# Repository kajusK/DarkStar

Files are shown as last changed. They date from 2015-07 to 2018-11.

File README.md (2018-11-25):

New version!
============

There's a whole new version with mutch more features and power:
https://github.com/kajusK/Darkstar-Mk.II/

DarkStar headlamp
=================

Small, lightweight and waterproof LED headlamp with two Cree XP-G2 leds. Can be
used in biking, caving, mine exploration, hiking... But **always** carry a
**backup** light source.

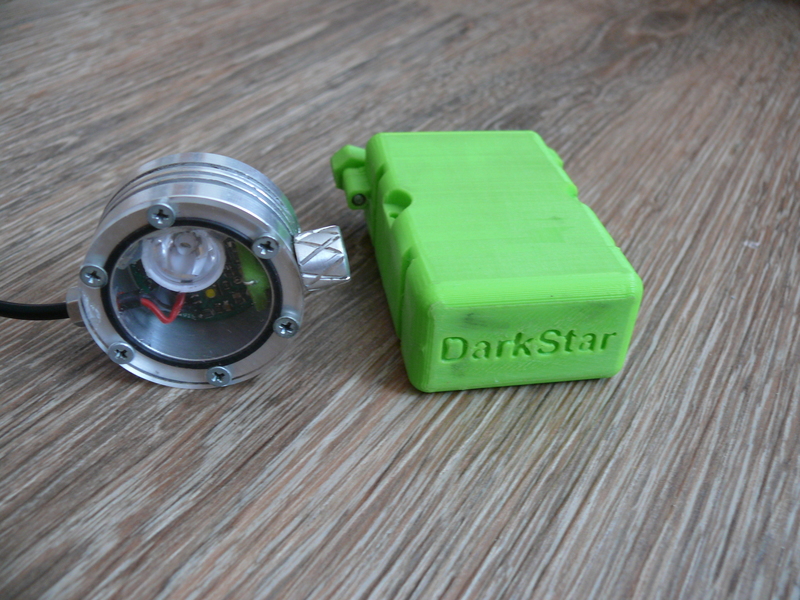
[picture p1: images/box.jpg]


Features
--------
* Waterproof aluminium lamp body
* Lightweight - whole headlamp, including two 18650 batteries, weights 220 grams
* Two 5W Cree XP-G2 LEDs with independently controlled brightness
* Always on LED with wide (115 degrees) beam to illuminate surroundings
* One narrow beam (10 degrees) LED to illuminate long tunnels, big caves, etc.
* Real Lab-measured light output is over 200lm (ebay value, based only on LED datasheet, would be over 600lm), see [Measurement](./Measurement.md) for more details
* Small red status LED (can be replaced by UV LED, etc.)
* Controlled by PIC 16F616 MCU (source code included)
* Low power off current (3,2 uA), no need to unplug battery during power off state
* Low power mode when battery is almost dead (single LED on lowest power, ~40mA)
* Long run time (up to 110 hours on lowest power (~40mA), over 24 hours on reasonable walking power (~150mA))
* 3D printed waterproof battery box for two 18650 Li-Ion cells

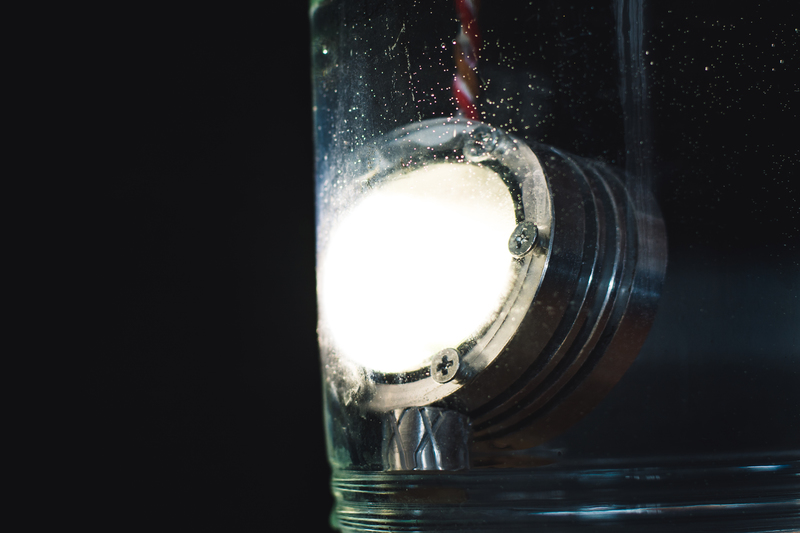
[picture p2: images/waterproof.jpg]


Weight
------
* Lamp head: 80g
* Battery box: 45g
* 2x18650 battery pack: 96g

Controls
--------
* Connect headlamp to battery, LEDs will flash and device goes to sleep
* Press and hold up button for about 2 seconds, first LED turns on
* Use up/down buttons to increase/decrease LEDs intensity
* Press and hold down button for about 2 seconds to turn on/off second LED
* When the second LED is on, use up/down buttons to control its intensity
* Press and hold up button for about 2 seconds to turn the lamp off

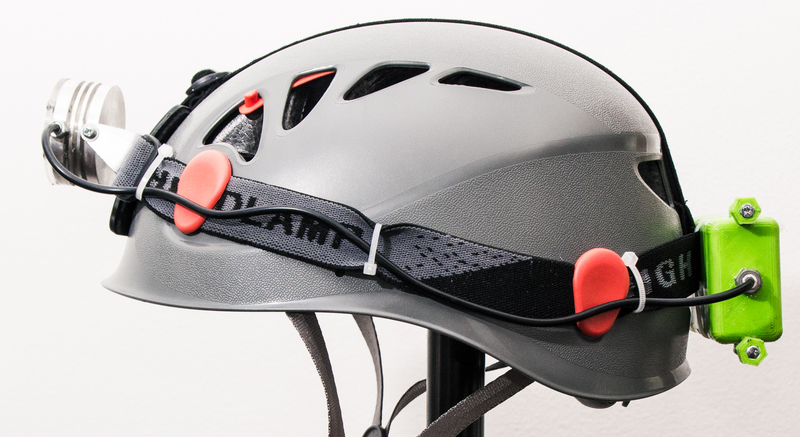
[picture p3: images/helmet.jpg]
Helmet


Warning
-------
Li-Ion cells can catch fire or explode if not handled properly. The hardware
design was NOT extensively tested, the headlamp could die any time, don't
rely on it as a single source of light.

The headlamp body can get quite hot if both LEDs are running on full power,
there's no thermal protection, **you have been warned**.

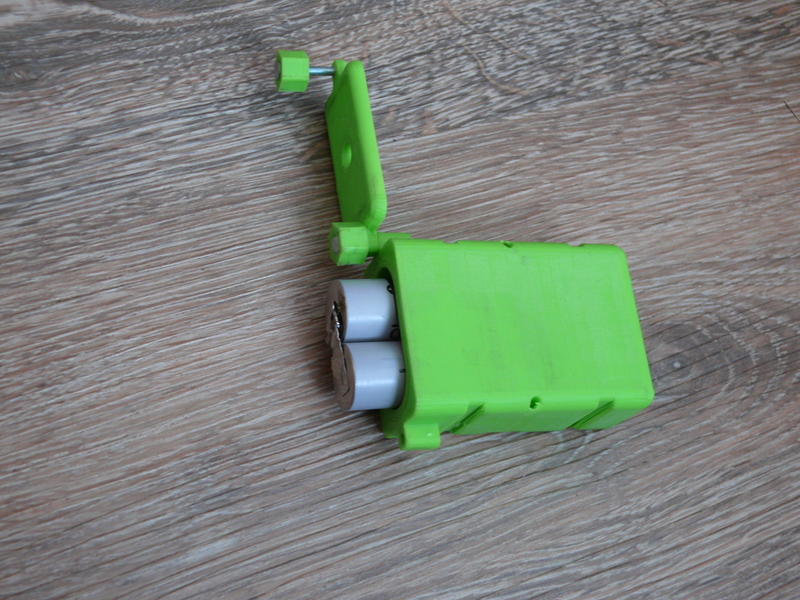
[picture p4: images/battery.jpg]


License
-------
This headlamp is provided under open source license WITHOUT ANY WARRANTY, see
[LICENSE](./LICENSE) for more details.

HowTo
=====
Directories
-----------
* **cad** headlamp body and battery box design (FreeCad)
* **pcb** contains all kicad files including BillOfMaterials for electronics,
	please note plated vias under Cree LEDs are mandatory to move heat from
	LED to heatsink (body). Gerber files for manufacturing are included.
* **pic** contains assembly source code for the headlamp MCU

Electronics & software
----------------------
For overview how the hardware works, check
[microchip application note](http://ww1.microchip.com/downloads/en/AppNotes/00874C.pdf)
and [source code README](./pic/README.md).

To reduce manufacturing costs, the heat from CREE LEDs is transferred to aluminium
body using several plated vias under the LED itself thus avoiding the need for
aluminium PCB or big star heat sink for each LED. For some math background, check
the [Cree thermal management guide](http://www.cree.com/~/media/Files/Cree/LED%20Components%20and%20Modules/XLamp/XLamp%20Application%20Notes/XLamp_PCB_Thermal.pdf).

Power wires are soldered directly to the PCB. To program the MCU, solder
wires to ICSP pins or build some kind of pin-touch interface. Use *make* in
pic directory to compile the sources (assuming you are running Linux),
you can use *make burn* to upload the firmware using pickit2.

Lenses
------
The wide beam LED can be used without lenses, the beam is wide enough for my
needs, for the narrow beam LED you can buy any compatible lens (it will require
some modifications due to limited space on PCB though). I used [17mm 10deg lens]
(http://www.aliexpress.com/item/Free-shipping-cree-xp-g-lens-Diameter-17mm-Smooth-surface-with-stand-Condenser-lenses-10-deg/777222733.html)

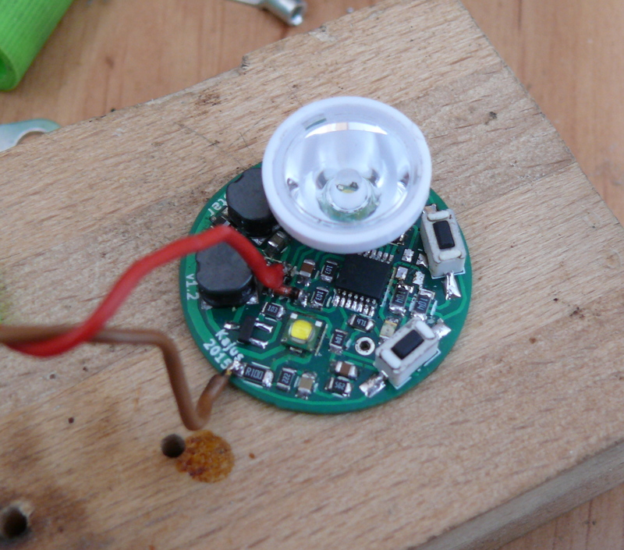
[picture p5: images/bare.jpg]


Body
----
The body is made from a piece of aluminium *6082 T6* using a small lathe. The top
cover is made from plexiglass taken from old diving goggles. Waterproofness is
ensured by big O-ring between body and glass and two small O-rings on the
control knob. The body works also as a heat sink for LEDs, therefore it cannot
be made from plastic (e.g. on 3D printer).

The battery box is printed on 3D printer from ABS (I would rather use aluminium,
but I don't have access to milling machine).

See [Bill of Materials](./BOM.md).

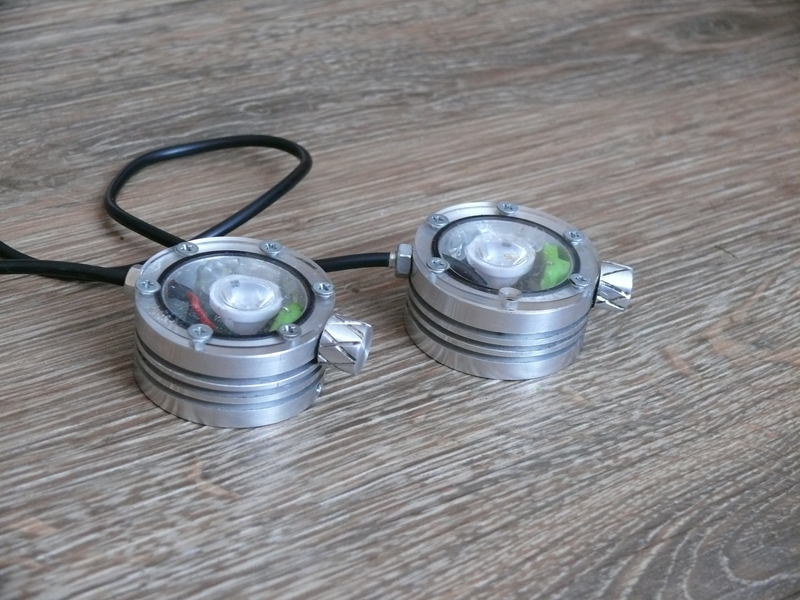
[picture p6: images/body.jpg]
Headlamp body


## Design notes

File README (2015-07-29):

Jakub Kaderka
jakub.kaderka@gmail.com
2015

Led headlamp based on PIC 16F616

=============================
Basic principle
=============================

PIC works as core of DC-DC step down converter. It has two internal independent
comparators which compare voltage on led sense resistor with a reference voltage
generated by PWM. The switching frequency is set by an external RC circuit to
about 100kHz.

The PIC generates two channel PWM signal (one for each led) which creates a
reference voltage after reducing the level by rezistor divider and smoothing
by RC circuit.

=============================
Implementation
=============================

The PWM is generated by software during interrupt routine (tmr0 overflows every
1ms). To keep it short and simple, the routine generates a shorter part of the
pulse. This way up to 50% of the system time is used for generator

If the PWM duty is over 50%, generate low part, if less than 50% generate high.

The rest of the programming is divided into two tasks: Key task and ADC task

--------------
Key task
--------------
Called every 10ms, it check the current key states and sets the flags. It's able
to detect two key press lengths. Short press and long press. The long press
generates two separate handler calls, first is generated when time the key
is pressed exceeds the long press threshold and the second event occurs when
the key is released.

Key handlers points to actions.asm file which contains definitions of led modes
etc.

--------------
ADC task
--------------
ADC task is called every 200ms, it checks the battery voltage and corrects
the PWM output to keep the reference voltage stable when the supply voltage
drops.

The way the voltage is measured is a little tricky, to keep the consumed power
during sleep as low as possible, the pic uses a status LED as a reference which
brings kind of reversed logic into the program.

When device goes to sleep, status led is turned off and consumes no power.

When the supply voltage drops, the voltage across led is kept at the same level.
Because PIC takes the supply voltage as a reference for AD module, the measured
AD data on LED are getting bigger as the voltage drops. The equations how to
calculate the voltage from AD data are discussed in more details in ad.asm

Anyway this solutions has also some disadvantages. Due to low pin count and
quite crowded PCB, it's connected between pwm output and one of the pins.
As the pwm output changes quite often, the interrupt must be disabled during
measurement, therefore ADC task cannot be called very often as it would make
pwm output quite unstable.

The second problem is that the voltage across LED is not 100% stable, it changes
a bit as the input voltage drops. To set the threshold correctly, the actual
voltage at 3V needs to be measured and used in calculations

=============================
Operations
=============================
After connecting device to power, it goes to sleep. Press bt1 for about 2 sec to
turn it on. Press it again for more than 2 sec to turn it off

Press bt2 for about 2 sec to activate/deactivate second led.

Short press of bt1 increases light output, bt2 decreases
Led1 is turned on all times except the power off state, led2 is controled by
long press of bt2 (on/off), long press bt2 also switches currently controled
led's intensity

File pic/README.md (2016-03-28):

Led headlamp based on PIC 16F616
================================

Basic principle
===============

PIC works as core of DC-DC step down converter. It has two internal independent
comparators which compare voltage on led sense resistor with a reference voltage
generated by PWM. The switching frequency is set by an external RC circuit to
about 100kHz.

The PIC generates two channel PWM signal (one for each led) which creates a
reference voltage after reducing the level by rezistor divider and smoothing
by RC circuit.

Implementation
==============

The PWM is generated by software during interrupt routine (tmr0 overflows every
512us). To keep it short and simple, the routine generates a shorter part of the
pulse. This way up to 50% of the system time is used for generator

If the PWM duty is over 50%, generate low part, if less than 50% generate high.

The rest of the programming is divided into two tasks: Key task and ADC task

Key task
--------
Called every 10ms, it check the current key states and sets the flags. It's able
to detect two key press lengths. Short press and long press. The long press
generates two separate handler calls, first is generated when the key
is pressed for over the minimal time and the second event occurs when
the key is released.

Key handlers points to actions.asm file which contains definitions of led modes
etc.

ADC task
--------
ADC task is running at 8Hz, it checks the battery voltage and shuts the headlamp
off if it's too low. It could be also used to correct PWM period to keep
the brightness stable during whole discharge cycle of the battery.

The way the voltage is measured is a little tricky, to keep the consumed power
during sleep as low as possible, the pic uses a status LED as a reference which
brings kind of reversed logic into the program.

When device goes to sleep, status led is turned off and consumes no power.

The voltage across led is kept at almost the same level which is not dependent on
battery voltage.

Because PIC takes the supply voltage as a reference for AD module, the measured
AD data on LED are getting bigger as the voltage drops. The equations to
calculate the voltage from AD data are discussed in more details in ad.asm

Anyway this solutions has also some disadvantages. Due to low pin count and
quite crowded PCB, it's connected between pwm output and one of the pins.
As the pwm output changes quite often, the interrupt must be disabled during
measurement, therefore ADC task cannot be called very often as it would make
pwm output quite unstable.

The second problem is that the voltage across LED is not 100% stable, it changes
a bit as the input voltage drops. To set the threshold correctly, the actual
voltage at 3V needs to be measured and used in calculations

Operations
==========
After connecting device to power, it goes to sleep. Press bt1 for about 2 sec to
turn it on. Press it again for more than 2 sec to turn it off

Press bt2 for about 2 sec to activate/deactivate second led.

Short press of bt1 increases light output, bt2 decreases
Led1 is turned on all times except the power off state, led2 is controled by
long press of bt2 (on/off), long press bt2 also switches currently controled
led's intensity

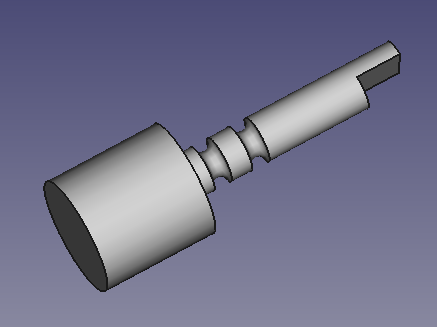
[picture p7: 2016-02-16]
images/cad/knob.png

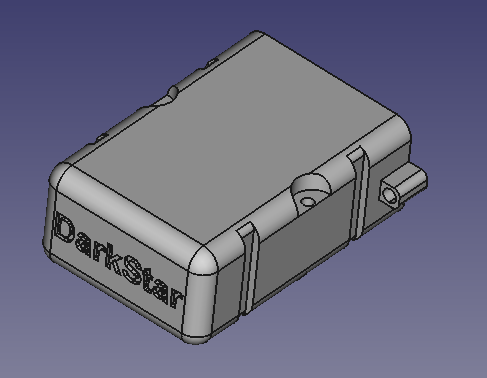
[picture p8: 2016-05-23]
images/cad/battery_box.png

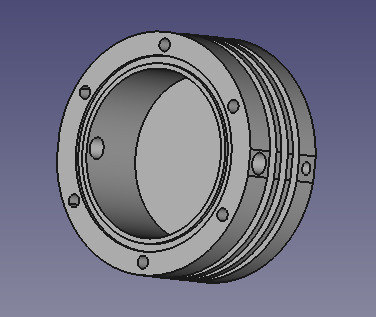
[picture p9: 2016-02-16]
images/cad/body.png

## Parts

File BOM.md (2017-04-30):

Bill Of Material
================

Mechanical only, for electronics see [BOM.csv](./pcb/BOM.csv).

| Item					| Amount|
|---|---|
| Aluminium 6082 T6, rod, diameter 50mm	| 25mm	|
| Aluminium 6082 T6, rod, diameter 15mm	| 45mm	|
| Plexi glass, 50x50 mm plate		| 1	|
| Screw M3x10, flat Phillips head	| 6	|
| Screw M3x10, hex head			| 6	|
| Screw M3x30, hex head			| 2	|
| Nut M3				| 1	|
| Spring washer M3			| 1	|
| Nut M5				| 1	|
| Nut M6				| 1	|
| Brass knurled nut M3			| 1	|
| O-ring 34x1,5				| 1	|
| O-ring 3x1				| 2	|
| O-ring 36x1,5				| 1	|
| Some ABS to print battery box		| 1	|
| 17mm condenser lens 10 deg for XP-G2	| 1	|

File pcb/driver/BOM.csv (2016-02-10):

Reference | Value | Footprint | Supplier
C1 | 470n | Capacitors_SMD:C_0805
C2 | 1u | Capacitors_SMD:C_0805
C4 | 1u | Capacitors_SMD:C_0805
C5 | 1n | Capacitors_SMD:C_0805
C6 | 1n | Capacitors_SMD:C_0805
C8 | 1u | Capacitors_SMD:C_0805
D1 | BAT60A | Diodes_SMD:SOD-323 | http://cz.farnell.com/infineon/bat-60a-e6327/rectifier-schottky-3a-10v-sod/dp/2432679
D4 | BAT60A | Diodes_SMD:SOD-323 | http://cz.farnell.com/infineon/bat-60a-e6327/rectifier-schottky-3a-10v-sod/dp/2432679
D7 | LED | LEDs:LED-0805 | http://cz.farnell.com/multicomp/ovs-0808/led-0805-super-brt-red-0-3cd-625nm/dp/1716768
D2 | LED1 | LEDs:LED-XP-G_CREE | http://cz.farnell.com/cree/xpgwht-0-1-0000-00gc2/led-od-wht-xpg-130lm-cct4500/dp/2062966
D5 | LED2 | LEDs:LED-XP-G_CREE | http://cz.farnell.com/cree/xpgwht-0-1-0000-00gc2/led-od-wht-xpg-130lm-cct4500/dp/2062966
D6 | LL103 | Diodes_SMD:Diode-MiniMELF_Standard | http://cz.farnell.com/vishay-semiconductor/ll103a-gs08/diode-schottky-40v-0-2a-sod-80/dp/1469389
L1 | 22uH | Choke_SMD:Choke_SMD_Wuerth-WE-PD2-Typ-MS | http://cz.farnell.com/bourns/srn6045-220m/inductor-power-22uh-semi-shielded/dp/2061654
L2 | 22uH | Choke_SMD:Choke_SMD_Wuerth-WE-PD2-Typ-MS | http://cz.farnell.com/bourns/srn6045-220m/inductor-power-22uh-semi-shielded/dp/2061654
P1 | POWER | Connect:GS2
P2 | ICSP | Housings_SOT-23_SOT-143_TSOT-6:SOT-143
Q1 | DMP2305U | Housings_SOT-23_SOT-143_TSOT-6:SOT-23_Handsoldering | http://cz.farnell.com/diodes-inc/dmp2305u-7/mosfet-p-ch-20v-4-2a-sot-23/dp/1858668
Q2 | DMP2305U | Housings_SOT-23_SOT-143_TSOT-6:SOT-23_Handsoldering | http://cz.farnell.com/diodes-inc/dmp2305u-7/mosfet-p-ch-20v-4-2a-sot-23/dp/1858668
R17 | 0R1 | Resistors_SMD:R_1206
R5 | 0R1 | Resistors_SMD:R_1206
R10 | 10k | Resistors_SMD:R_0805
R11 | 10k | Resistors_SMD:R_0805
R13 | 10k | Resistors_SMD:R_1206
R14 | 10k | Resistors_SMD:R_0805
R15 | 10k | Resistors_SMD:R_1206
R2 | 10k | Resistors_SMD:R_0805
R3 | 180k | Resistors_SMD:R_0805
R6 | 180k | Resistors_SMD:R_0805
R18 | 2k2 | Resistors_SMD:R_0805
R8 | 2k2 | Resistors_SMD:R_0805
R19 | 470R | Resistors_SMD:R_0805
R4 | 5k6 | Resistors_SMD:R_0805
R7 | 5k6 | Resistors_SMD:R_0805
R1 | 82R | Resistors_SMD:R_0805
R12 | 82R | Resistors_SMD:R_0805
SW1 | UP | Buttons_Switches_SMD:SW_SPST_FSMSM | http://cz.farnell.com/te-connectivity-alcoswitch/fsmsm/switch-spst-0-05a-24vdc-smd/dp/1703878
SW2 | DOWN | Buttons_Switches_SMD:SW_SPST_FSMSM | http://cz.farnell.com/te-connectivity-alcoswitch/fsmsm/switch-spst-0-05a-24vdc-smd/dp/1703878
U1 | PIC16(L)F616-I/ST | Housings_SSOP:TSSOP-14_4.4x5mm_Pitch0.65mm | http://cz.farnell.com/microchip/pic16f616-i-st/mcu-8bit-pic16-20mhz-tssop-14/dp/1467798

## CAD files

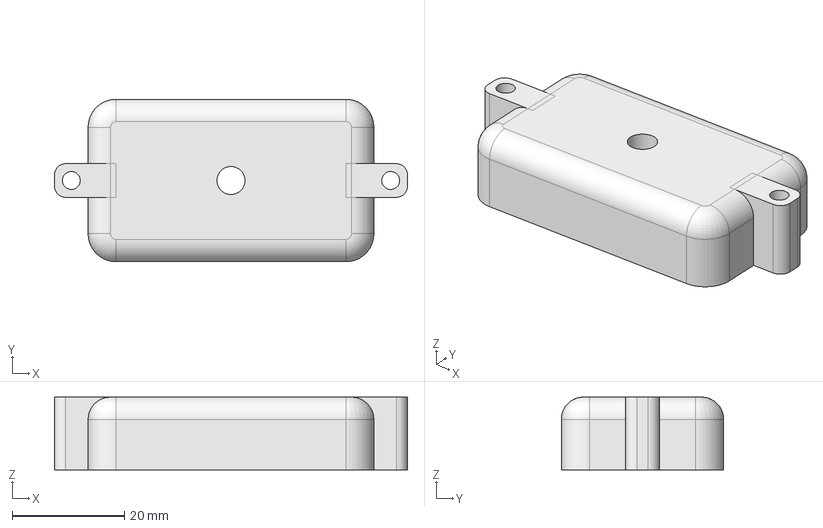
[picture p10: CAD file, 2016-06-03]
cad/battery_box/box_lid.fcstd
63.0 x 29.0 x 13.0 mm

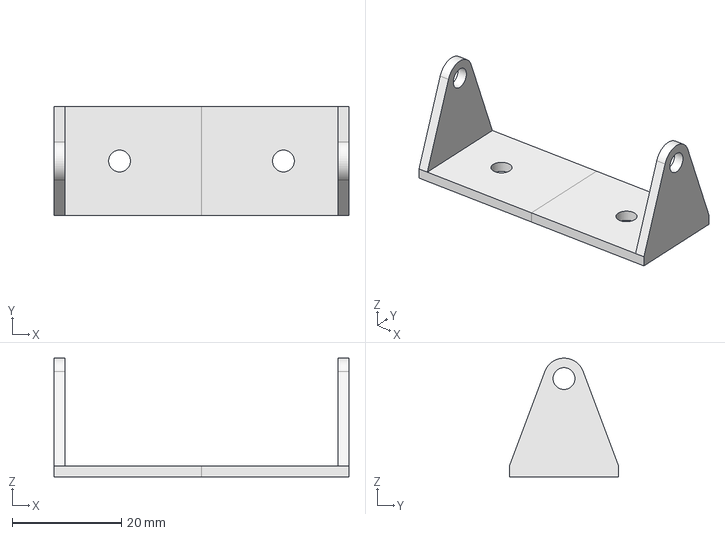
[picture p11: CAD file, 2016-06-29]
cad/body/holder.fcstd
54.0 x 20.0 x 21.7 mm

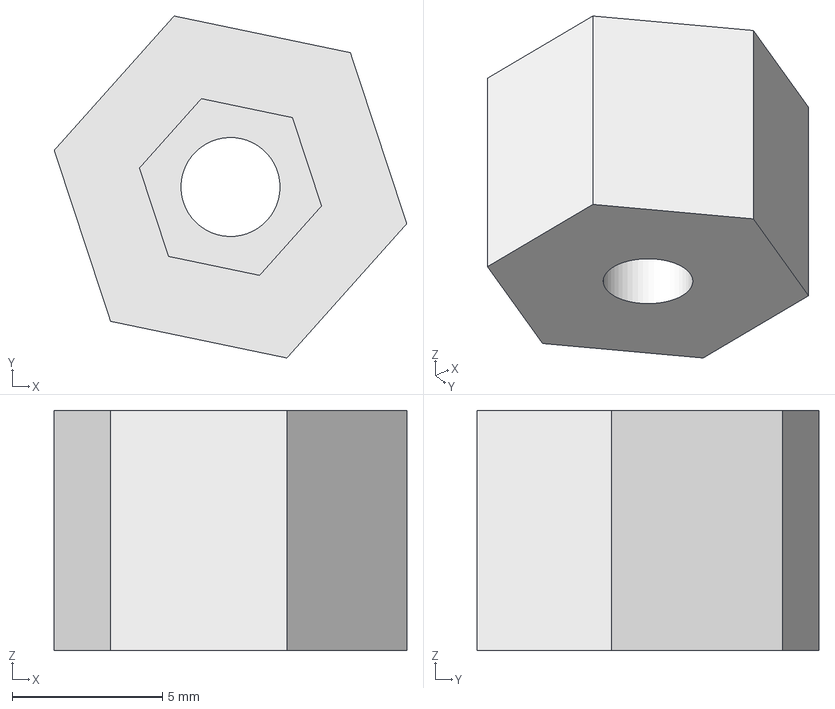
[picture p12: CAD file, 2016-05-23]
cad/battery_box/knob.fcstd
11.7 x 11.4 x 8.00 mm

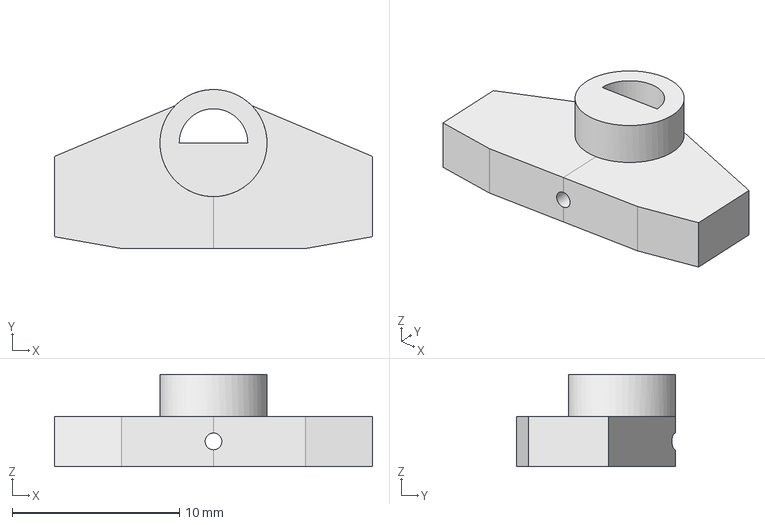
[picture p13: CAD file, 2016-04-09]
cad/body/switch.fcstd
19.0 x 9.50 x 5.50 mm

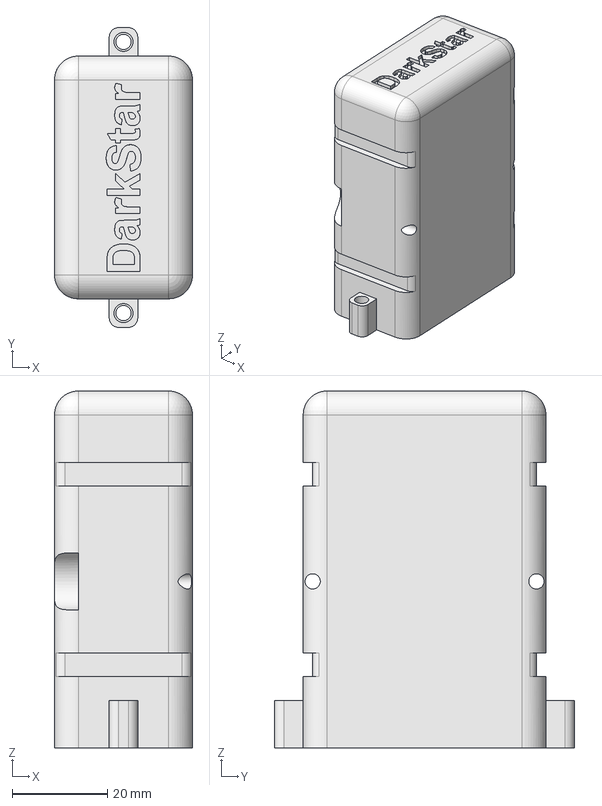
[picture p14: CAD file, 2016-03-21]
cad/battery_box/box_body.fcstd
29.0 x 63.0 x 75.0 mm

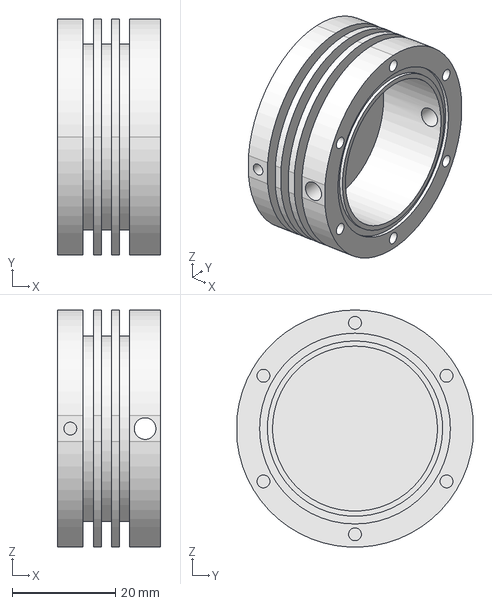
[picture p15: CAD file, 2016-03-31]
cad/body/body.fcstd
20.0 x 45.7 x 46.0 mm

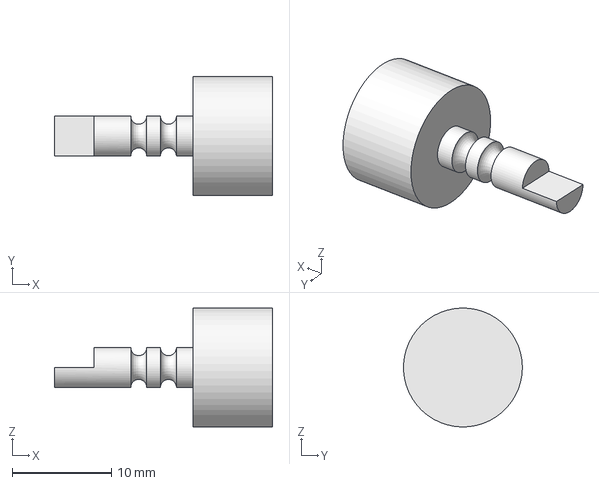
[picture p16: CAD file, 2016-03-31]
cad/body/control_knob.fcstd
22.0 x 12.0 x 12.0 mm

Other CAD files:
cad/battery_box/box_body.stl
cad/battery_box/box_lid.stl
cad/battery_box/knob.stl
cad/body/switch.stl

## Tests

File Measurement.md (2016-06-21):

Laboratory measurement
======================

The light output of DarkStar headlamp was measured in light lab of Faculty
of Electrical Engineering of Brno University of Technology in
[Integrating sphere](https://en.wikipedia.org/wiki/Integrating_sphere).

The results can bee see in [Measure_results.csv](./Measure_results.csv),
first 7 measurements were run with only one LED at the maximum output power
(not the full 5W declared by manufacturer, but only about 3W to reduce heating).
Remaining columns are measured when running on full output setting on both LEDs.

The result of heating can be seen immediately, the light output drops from
the initial 104lm in cold state to 97lm (214lm to 195lm in full power configuration).
Expected light output on full power was around 300lm, however, this value is based
on datasheed, the real output is lower due to lower efficiency of LED working
on higher temperatures, losses in the optics and plexi cover, etc.

The Correlated Colour Temperature (CCT) is between 4550 and 4900 Kelvins (depending
on current power output). The dominant wavelenght is around 575nm.

The relative spectral power distribution quite matches the datasheet graph:
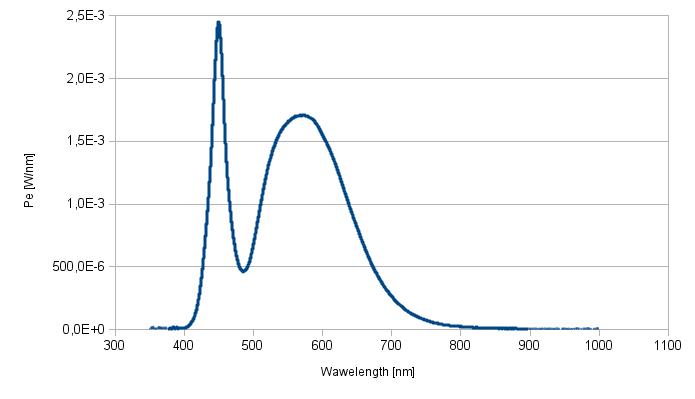
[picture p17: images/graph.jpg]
Relative spectral power distribution


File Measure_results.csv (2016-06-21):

Measurement number | #1 | #2 | #3 | #4 | #5 | #6 | #7 | #8 | #9 | #10 | #11 | #12
Correction | UV | UV | UV | UV | UV | UV | UV | UV | UV | UV | UV | UV
Time | 10:44:48 | 10:46:53 | 10:48:59 | 10:51:04 | 10:53:10 | 10:55:16 | 10:57:21 | 10:59:30 | 11:01:20 | 11:03:11 | 11:05:04 | 11:06:57
Integration Time [ms] | 1524.000 | 1568.000 | 1570.000 | 1584.000 | 1579.000 | 1598.000 | 1602.000 | 763.000 | 792.000 | 807.000 | 830.000 | 833.000
Luminous Flux [lm] | 104.4 | 101.6 | 100.9 | 99.5 | 98.4 | 97.6 | 97.2 | 214.6 | 207.9 | 203.2 | 199.1 | 195.6
Radiant Flux [W] (230-1000nm) | 0.327 | 0.319 | 0.317 | 0.313 | 0.309 | 0.307 | 0.306 | 0.664 | 0.644 | 0.631 | 0.618 | 0.608
Correlated Colour Temp. (CCT) [K] | 4831 | 4837 | 4843 | 4848 | 4854 | 4858 | 4861 | 4568 | 4568 | 4570 | 4571 | 4572
Duv | 0.000 | 0.000 | 0.000 | 0.000 | 0.000 | 0.000 | 0.000 | 0.003 | 0.003 | 0.003 | 0.003 | 0.003
Dominant Wavelength (DWl) [nm] | 574.5 | 574.5 | 574.4 | 574.3 | 574.2 | 574.2 | 574.2 | 574.6 | 574.6 | 574.6 | 574.5 | 574.5
Dominant Wavelength (DWl) [nm] (10° observer) | 577.6 | 577.4 | 577.3 | 577.2 | 577.1 | 577.0 | 576.9 | 574.8 | 574.7 | 574.6 | 574.5 | 574.5
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

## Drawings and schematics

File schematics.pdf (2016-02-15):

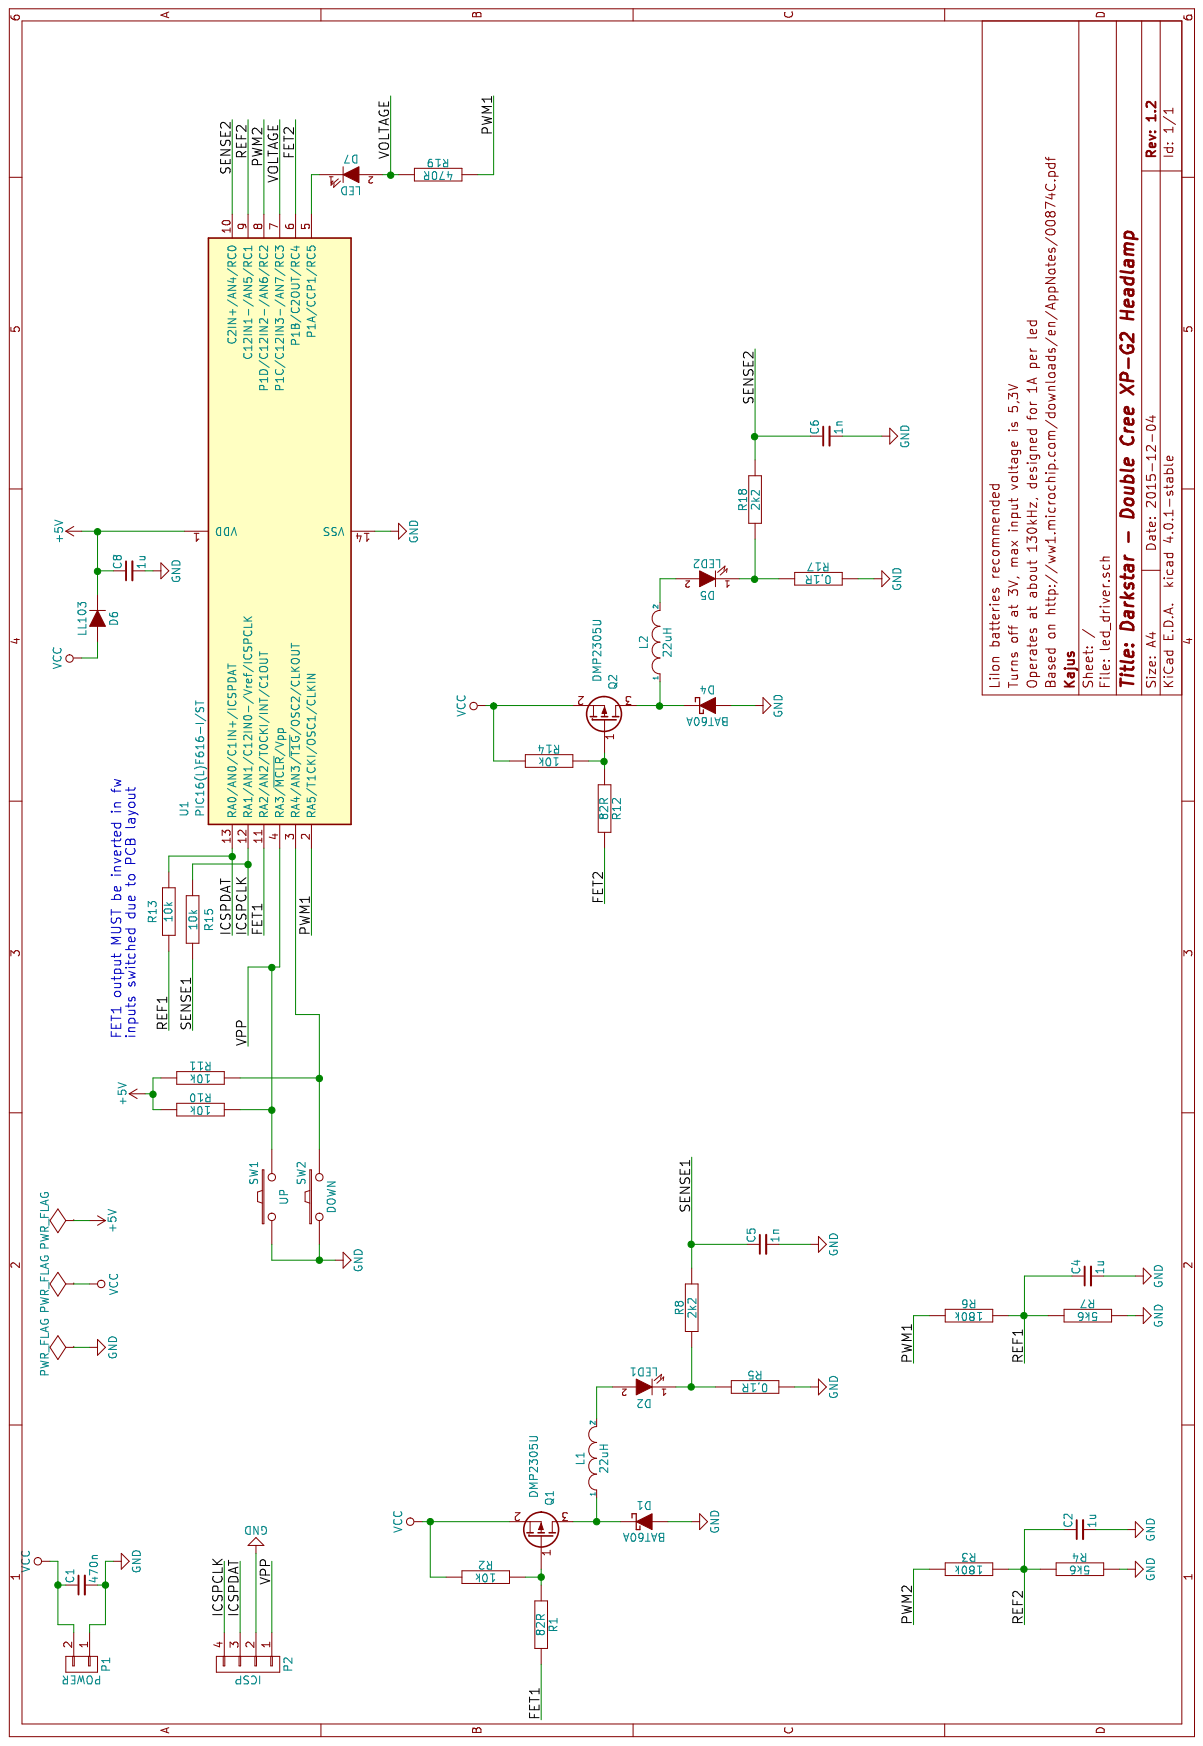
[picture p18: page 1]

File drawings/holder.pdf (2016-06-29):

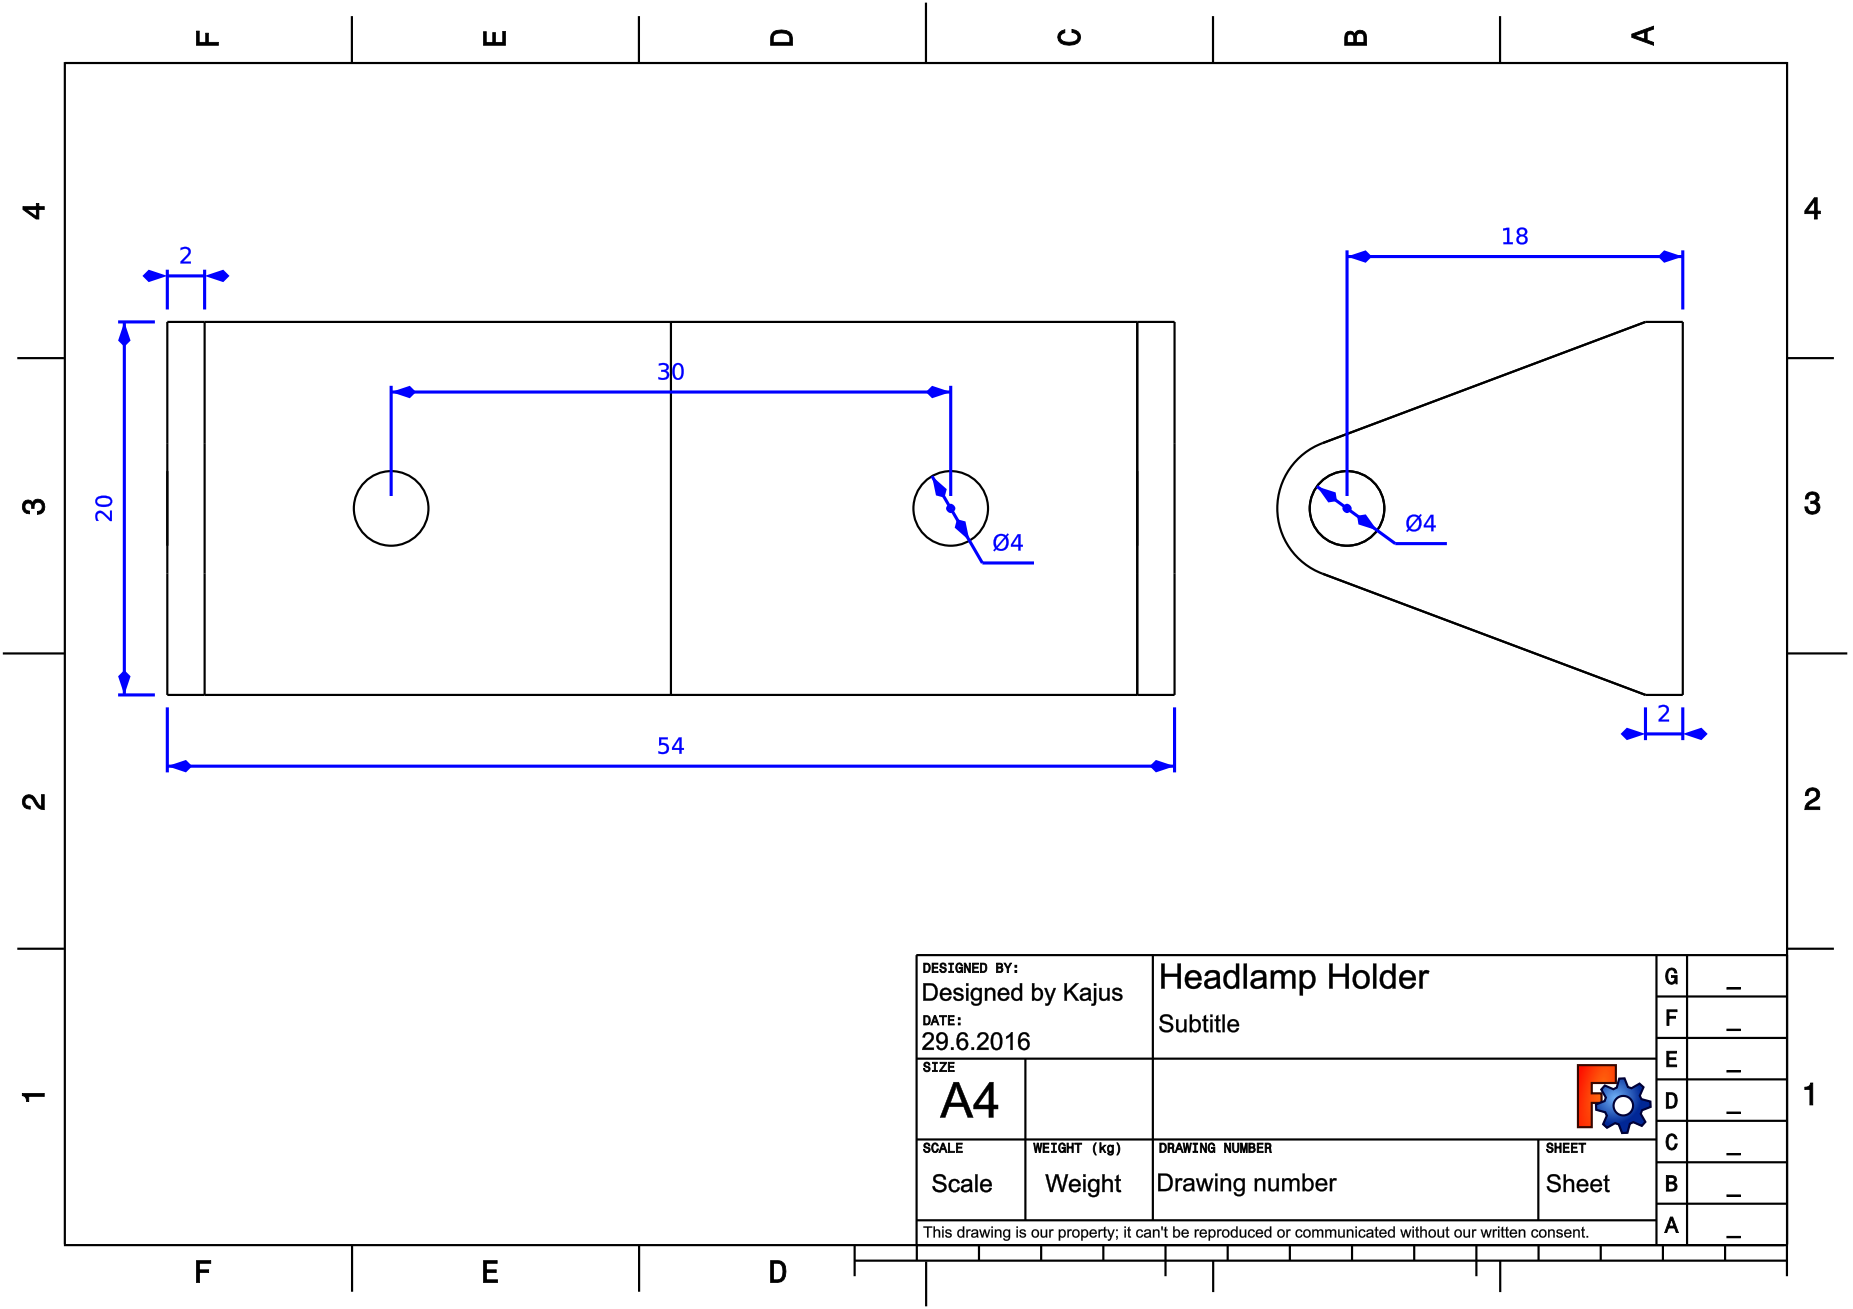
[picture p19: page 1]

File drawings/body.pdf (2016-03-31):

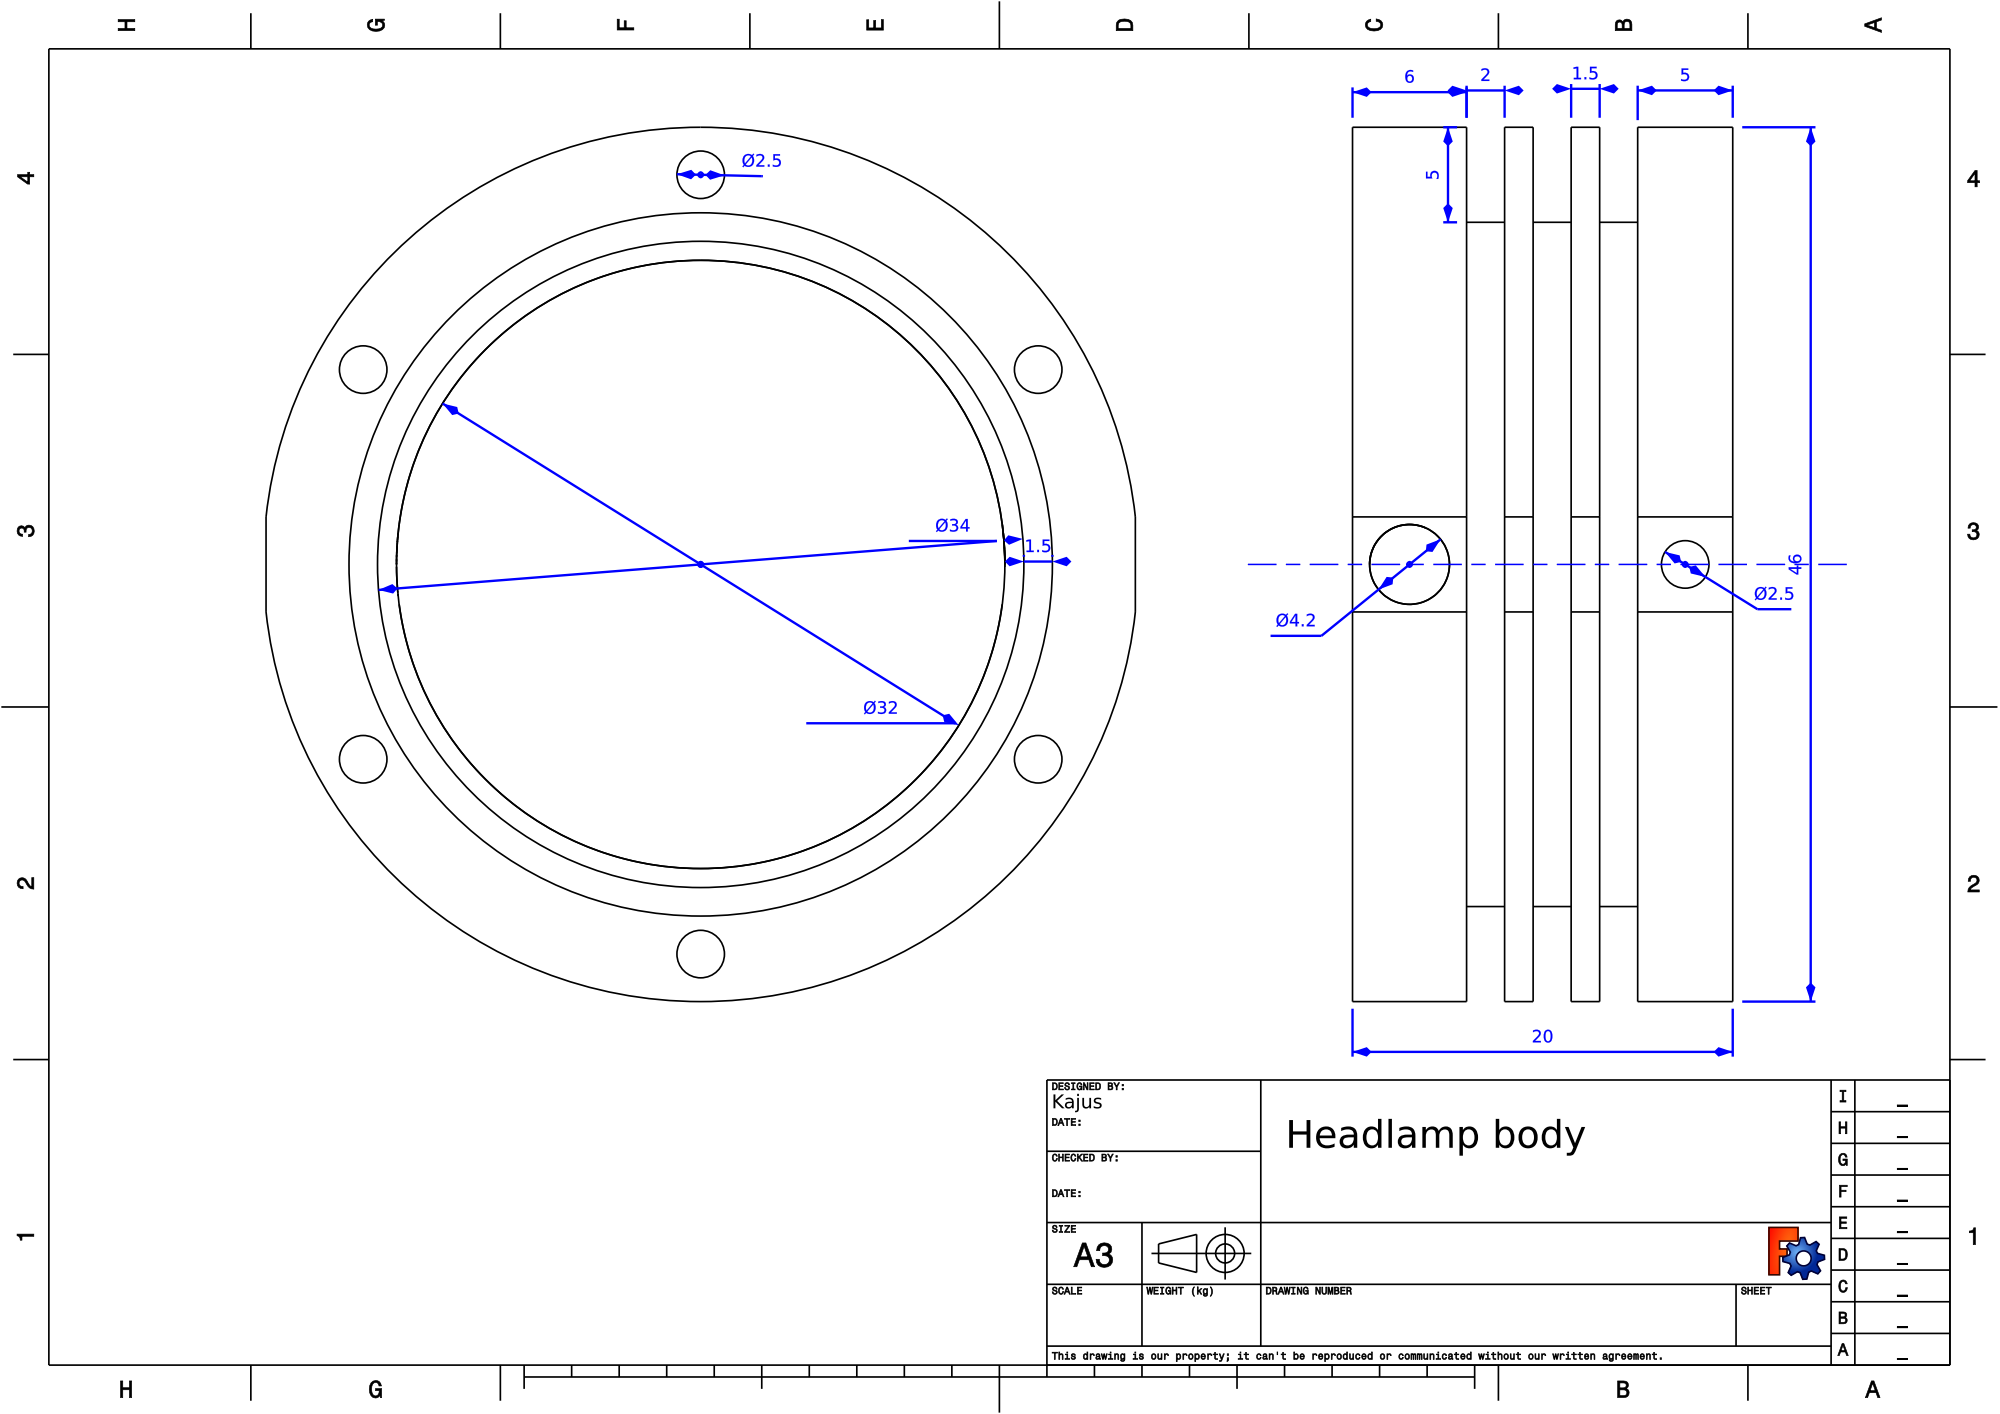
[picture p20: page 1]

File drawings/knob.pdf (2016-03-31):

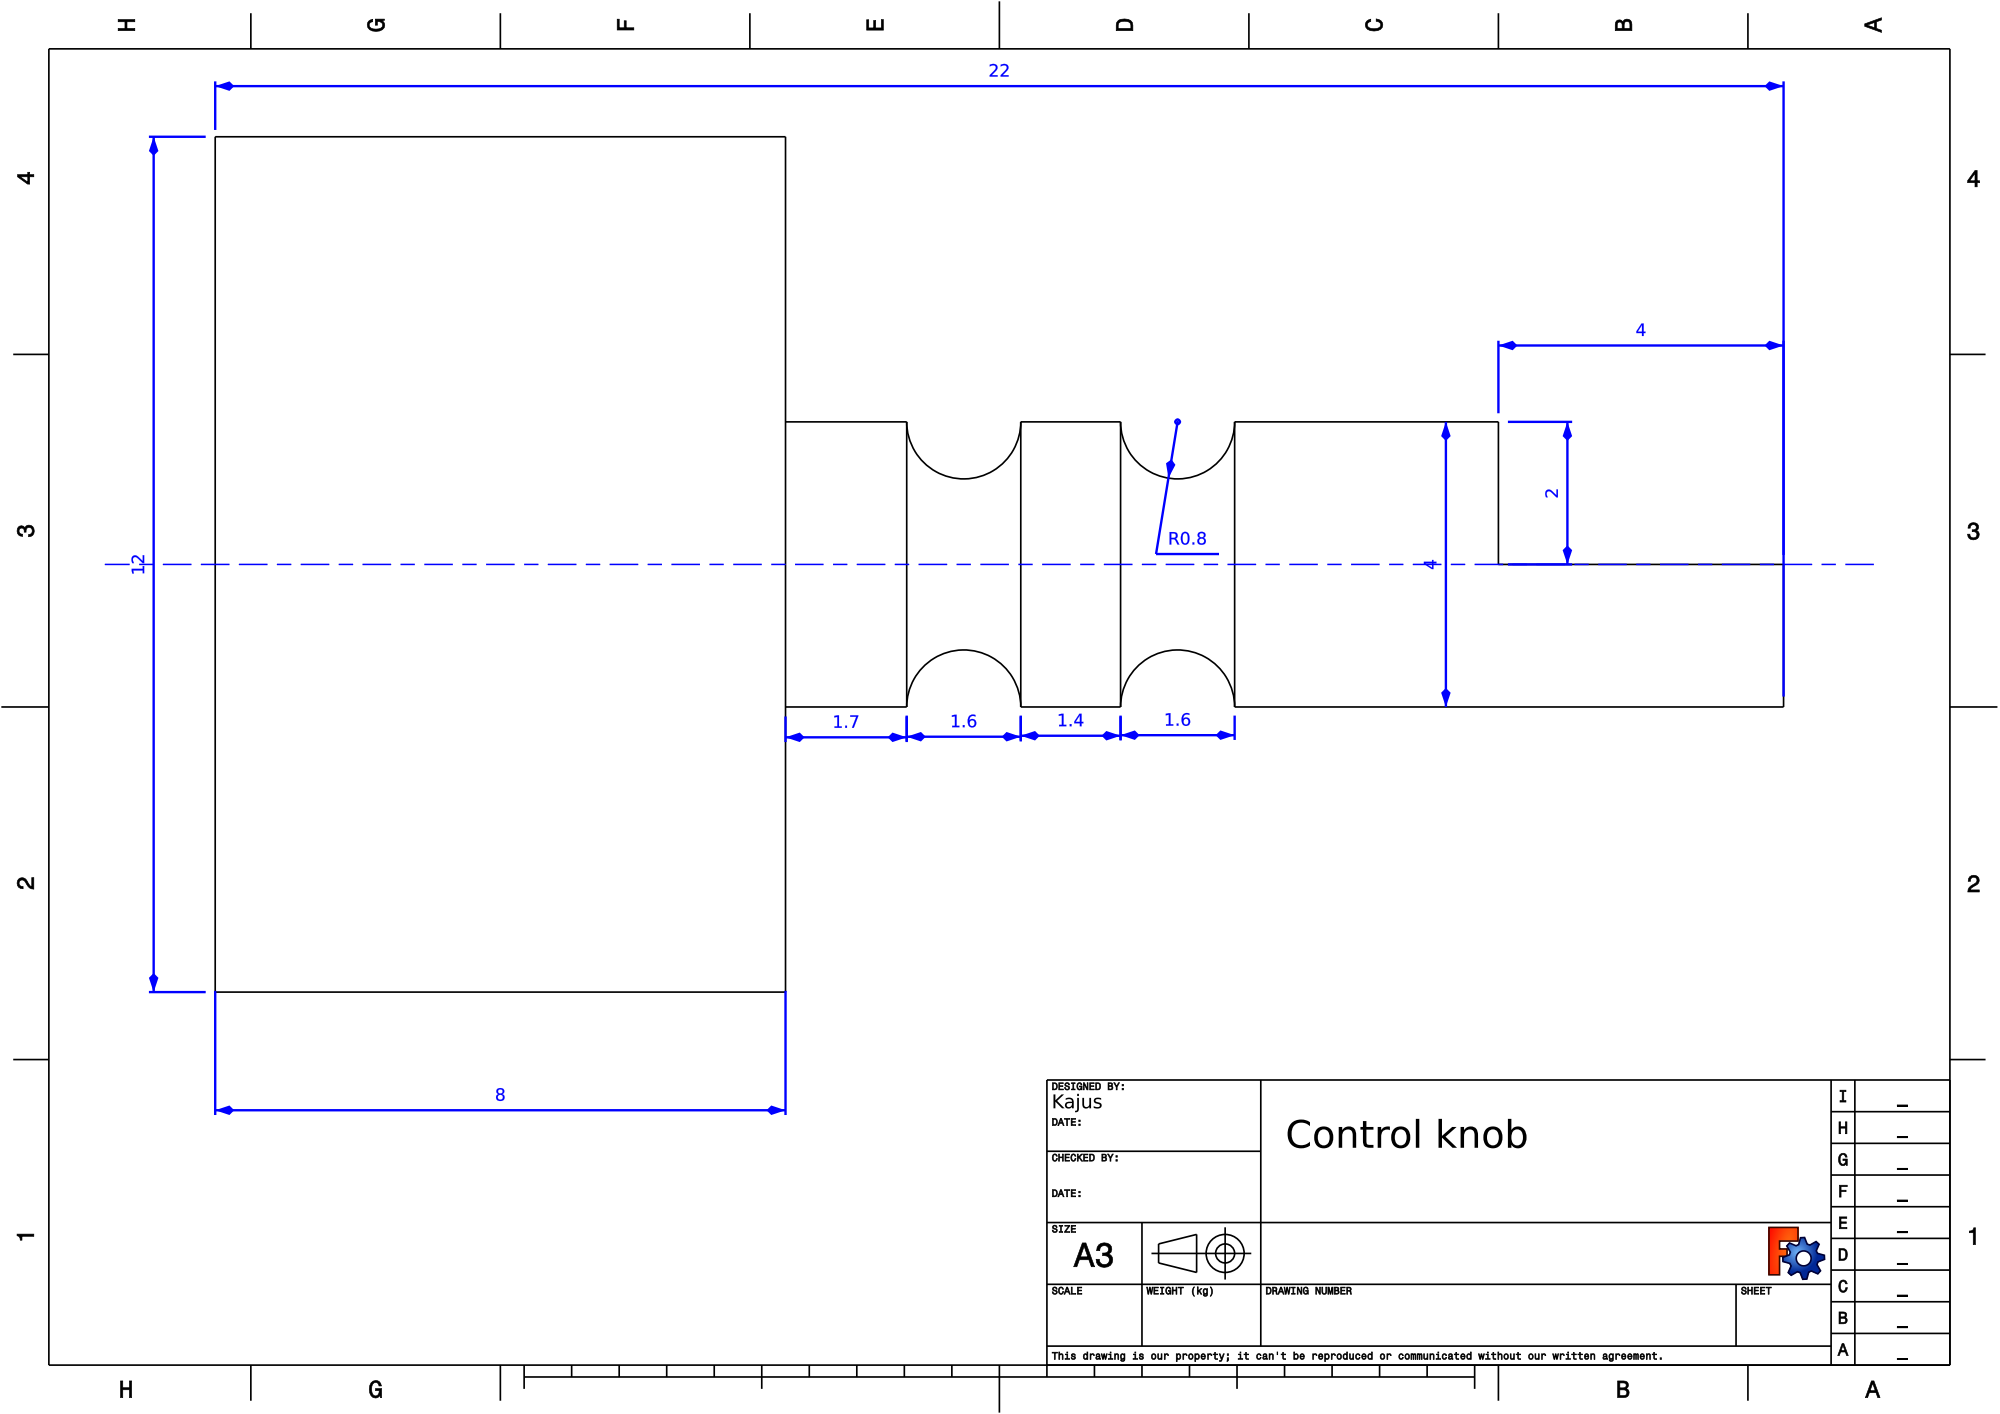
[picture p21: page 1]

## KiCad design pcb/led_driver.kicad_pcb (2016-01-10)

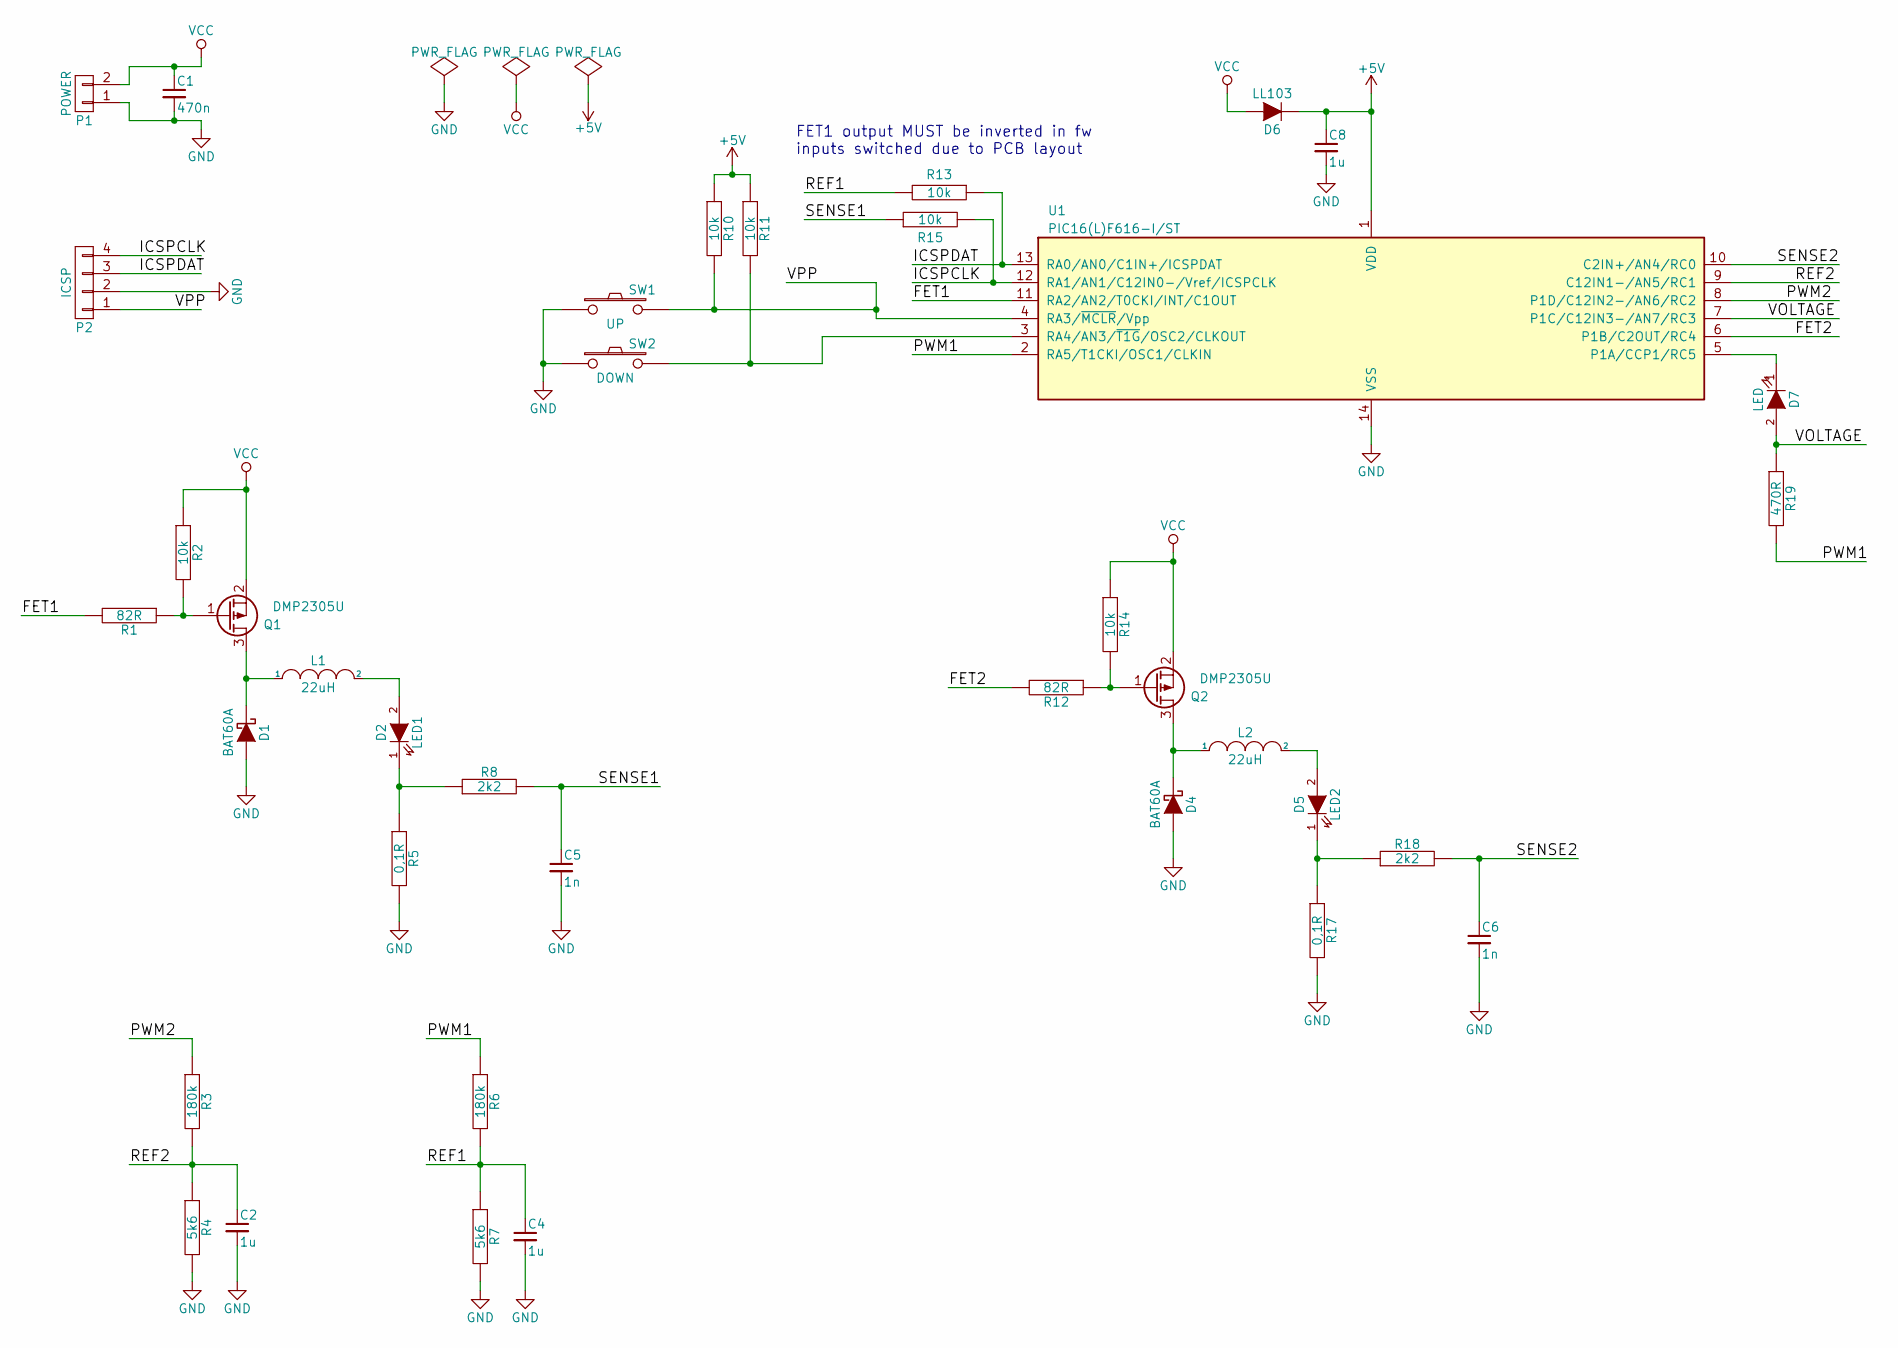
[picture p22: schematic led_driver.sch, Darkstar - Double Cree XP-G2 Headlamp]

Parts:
C1: 470n; C_0805
C2, C4, C8: 1u; C_0805
C5, C6: 1n; C_0805
D1, D4: BAT60A; SOD-323
D2: LED1; LED-XP-G_CREE
D5: LED2; LED-XP-G_CREE
D6: LL103; Diode-MiniMELF_Standard
D7: LED; LED-0805
L1, L2: 22uH; Choke_SMD_Wuerth-WE-PD2-Typ-MS
P1: POWER; GS2
P2: ICSP; SOT-143
Q1, Q2: DMP2305U; SOT-23_Handsoldering
R1, R12: 82R; R_0805
R2, R10, R11, R14: 10k; R_0805
R3, R6: 180k; R_0805
R4, R7: 5k6; R_0805
R5, R17: 0,1R; R_1206
R8, R18: 2k2; R_0805
R13, R15: 10k; R_1206
R19: 470R; R_0805
SW1: UP; SW_SPST_FSMSM
SW2: DOWN; SW_SPST_FSMSM
U1: PIC16(L)F616-I/ST; TSSOP-14_4.4x5mm_Pitch0.65mm

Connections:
+5V: C8.1, D6.1 (K), R10.1, R11.1, U1.1 (VDD)
/FET1: R1.2, U1.11 (RA2/AN2/T0CKI/INT/C1OUT)
/FET2: R12.2, U1.6 (P1B/C2OUT/RC4)
/HEATSINK: D2.3, D5.3
/ICSPCLK: P2.4, R15.2, U1.12 (RA1/AN1/C12IN0-/Vref/ICSPCLK)
/ICSPDAT: P2.3, R13.1, U1.13 (RA0/AN0/C1IN+/ICSPDAT)
/PWM1: R6.1, R19.2, U1.2 (RA5/T1CKI/OSC1/CLKIN)
/PWM2: R3.1, U1.8 (P1D/C12IN2-/AN6/RC2)
/REF1: C4.1, R6.2, R7.1, R13.2
/REF2: C2.1, R3.2, R4.1, U1.9 (C12IN1-/AN5/RC1)
/SENSE1: C5.1, R8.2, R15.1
/SENSE2: C6.1, R18.2, U1.10 (C2IN+/AN4/RC0)
/VOLTAGE: D7.2 (A), R19.1, U1.7 (P1C/C12IN3-/AN7/RC3)
/VPP: P2.1, R10.2, SW1.2, U1.4 (RA3/~MCLR~/Vpp)
GND: C1.2, C2.2, C4.2, C5.2, C6.2, C8.2, D1.2 (A), D4.2 (A), P1.1, P2.2, R4.2, R5.2, R7.2, R17.2, SW1.1, SW2.1, U1.14 (VSS)
unnamed: D1.1 (K), L1.1, Q1.3 (D)
unnamed: D2.1 (K), R5.1, R8.1
unnamed: D2.2 (A), L1.2
unnamed: D4.1 (K), L2.1, Q2.3 (D)
unnamed: D5.1 (K), R17.1, R18.1
unnamed: D5.2 (A), L2.2
unnamed: D7.1 (K), U1.5 (P1A/CCP1/RC5)
unnamed: Q1.1 (G), R1.1, R2.2
unnamed: Q2.1 (G), R12.1, R14.2
unnamed: R11.2, SW2.2, U1.3 (RA4/AN3/~T1G~/OSC2/CLKOUT)
VCC: C1.1, D6.2 (A), P1.2, Q1.2 (S), Q2.2 (S), R2.1, R14.1

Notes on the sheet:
FET1 output MUST be inverted in fw inputs switched due to PCB layout

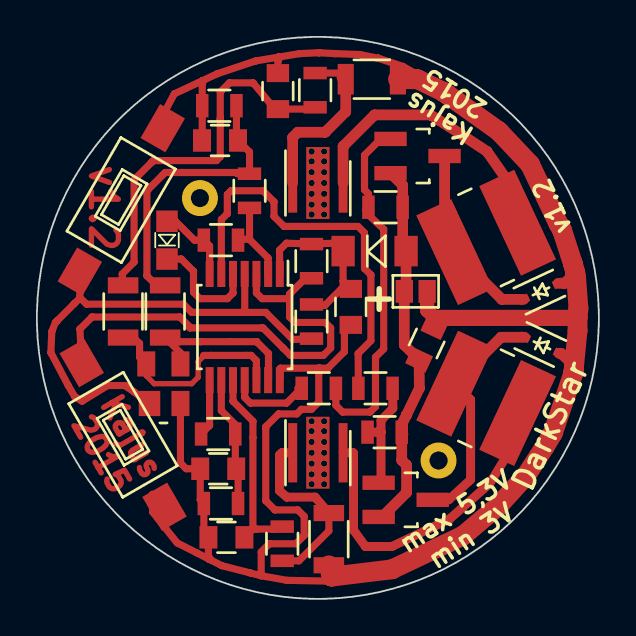
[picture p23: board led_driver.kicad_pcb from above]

Board: 2 copper layers, 31.2 x 31.2 mm, 38 parts (0 on the bottom side), 26 nets.

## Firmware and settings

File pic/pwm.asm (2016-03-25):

;**********************************************************************
;Led headlamp
;PIC 16F616
;internal 8MHz
;------------------------------
; Jakub Kaderka
; jakub.kaderka@gmail.com
; 2015
;------------------------------
; pwm.asm
;------------------------------
; Pwm generator uses tmr0 interrupt which sets the pwm frequency (2048Hz),
; After the timer overflow, pwm outputs are driven to high or low, based
; on the pwm duties:
;	duty <= 50% : set pin to high
;	duty >= 50% : set pin to low
;
; Then after time given by pwm_time1 toggles pin which corresponds to
; shorted pulse and wait for pwm_time2 loops. Finally, the second pin
; is toggled and the interrupt routine ends.
;
; This design takes up to 50% of the processing (pwm at 50%) time without
; depending ; on precise timing of other system jobs.
;
;
; To make interrupt routine as short as possible, the necessary pin
; output values and timing variables are calculated by pwm_update routine
; only once per pwm duty update.
;
; As the voltage drops with battery closing to end of it's capacity,
; the voltage generated by pwm is also decreasing. Therefore the AD
; task measures voltage few times a second and calculates necessary
; correction to pwm duty to keep the voltage stable.
;**********************************************************************
;---------------------------
; set outputs to values from pwm_data
; par1 and par2 defines bits to read
;---------------------------
PWM_SET macro par1, par2
	bcf	pwm1
	btfsc	pwm_data, par1
	bsf	pwm1

	bcf	pwm2
	btfsc	pwm_data, par2
	bsf	pwm2
	endm

;---------------------------
; set pwm_tmp_data, par1 to 1 if pwm_tmp_data, par2 is 0
;---------------------------
PWM_TOGGLE_CONF macro par1, par2
	bcf	pwm_tmp_data, par1
	btfss	pwm_tmp_data, par2
	bsf	pwm_tmp_data, par1
	endm

;---------------------------
; set pwm_tmp_data, par1 to pwm_tmp_data, par2
;---------------------------
PWM_COPY_CONF macro par1, par2
	bcf	pwm_tmp_data, par1
	btfsc	pwm_tmp_data, par2
	bsf	pwm_tmp_data, par1
	endm

;-----------------------------------
; Update pwm generator duties
;
; calculate variables for pwm generator (based on pwm_dutyX)
; and update them when finished
;
; Calculated values sets the time of the shorter pulse (pwm_time1)
; and the difference between shorter and longer part (pwm_time2)
;
; States of the outputs in each of the three parts of the pwm
; executions (initial, firts pulse finished, second finished)
; are stored in pwm_data
;
; disables interrupts momentarily
;-----------------------------------
pwm_update
	clrf	pwm_tmp_data

;first get initial values and timing of shorter part of the pulse
	movlw	PWM_DUTY_HALF
	subwf	pwm_duty1, w		;compare 50% and actual value
	btfsc	status, c
	goto	pwm_update_2		;over 50%

	bsf	pwm_tmp_data, pstart1	;under 50%
	movf	pwm_duty1, w
	movwf	pwm_tmp1		;just copy the duty for further computation

pwm_update_1
	movlw	PWM_DUTY_HALF
	subwf	pwm_duty2, w		;compare 50% and actual value
	btfsc	status, c
	goto	pwm_update_3		;over 50%

	bsf	pwm_tmp_data, pstart2	;under 50%
	movf	pwm_duty2, w
	movwf	pwm_tmp2		;just copy the duty for further computation

	goto	pwm_update_4

;duty1 over 50
pwm_update_2
	movf	pwm_duty1, w
	sublw	PWM_DUTY_FULL	;PWM_DUTY_FULL - pwm_duty
	movwf	pwm_tmp1
	goto	pwm_update_1

;duty2 over 50
pwm_update_3
	movf	pwm_duty2, w
	sublw	PWM_DUTY_FULL	;PWM_DUTY_FULL - pwm_duty
	movwf	pwm_tmp2

;first bits and times are ready, compute middle and end bits
pwm_update_4
	movf	pwm_tmp1, w
	subwf	pwm_tmp2, w		;tmp2 - tmp1
	btfsc	status, z
	goto	pwm_update_same		;tmp2 == tmp1

	btfss	status, c
	goto	pwm_update_5		;tmp1 > tmp2
;tmp1 < tmp2
	PWM_TOGGLE_CONF pmiddle1, pstart1
	PWM_COPY_CONF	pmiddle2, pstart2
	PWM_TOGGLE_CONF pend2, pmiddle2
	PWM_COPY_CONF	pend1, pmiddle1

	movf	pwm_tmp1, w
	movwf	pwm_tmp_time1		;update shorter pulse time

	subwf	pwm_tmp2, w
	movwf	pwm_tmp_time2		;tmp2-tmp1
	goto	pwm_update_var		;set the permanent values and return

;tmp1 > tmp2
pwm_update_5
	PWM_TOGGLE_CONF pmiddle2, pstart2
	PWM_COPY_CONF	pmiddle1, pstart1
	PWM_TOGGLE_CONF pend1, pmiddle1
	PWM_COPY_CONF	pend2, pmiddle2

	movf	pwm_tmp2, w
	movwf	pwm_tmp_time1		;update shorter pulse time

	subwf	pwm_tmp1, w
	movwf	pwm_tmp_time2		;tmp1-tmp2
	goto	pwm_update_var		;set the permanent values and return

;both pwm times are same
pwm_update_same
	PWM_TOGGLE_CONF	pmiddle1, pstart1
	PWM_TOGGLE_CONF	pmiddle2, pstart2
	PWM_COPY_CONF	pend1, pmiddle1
	PWM_COPY_CONF	pend2, pmiddle2	;toggle middle and copy middle to end
	clrf	pwm_tmp_time2
	movf	pwm_tmp1, w
	movwf	pwm_tmp_time1		;update time1 to pulse length and time2 to 0
	goto	pwm_update_var		;finally, update the real pwm values

;finally, copy values from tmp to permanent locations
;additionally, check for 100% or 0% duty cycles and update the data parts
;disables interrupts mometarily!
pwm_update_var
;final checks, fix the max/min duty variables
	movf	pwm_tmp1, f
	btfsc	status, z
	goto	pwm_update_var_1	;pwm1 is 100% or 0%
pwm_update_var_3
	movf	pwm_tmp2, f
	btfsc	status, z
	goto	pwm_update_var_2

pwm_update_var_4
;update the times to avoid owerflow - pwm generator first do decfsz...
	incf	pwm_tmp_time1, w
	btfss	status, z		;check if incrementing wont't cause buffer overflow
	incf	pwm_tmp_time1, f

	incf	pwm_tmp_time2, w
	btfss	status, z
	incf	pwm_tmp_time2, f
;disable interrupts and copy data to the permanent location
	bcf	intcon, gie		;disable interrupt
	movf	pwm_tmp_data, w
	movwf	pwm_data
	movf	pwm_tmp_time1, w
	movwf	pwm_time1
	movf	pwm_tmp_time2, w
	movwf	pwm_time2		;copy data
	bsf	intcon, gie		;reenable interrupt
	return

;pwm 1 on 100% or 0%
pwm_update_var_1
	PWM_TOGGLE_CONF	pstart1, pstart1
	PWM_COPY_CONF	pmiddle1, pstart1
	PWM_COPY_CONF	pend1, pmiddle1
	goto		pwm_update_var_3

;pwm 2 on 100% or 0%
pwm_update_var_2
	PWM_TOGGLE_CONF	pstart2, pstart2
	PWM_COPY_CONF	pmiddle2, pstart2
	PWM_COPY_CONF	pend2, pmiddle2
	goto		pwm_update_var_4

;-----------------------------------
; Limit value in W to PWM_DUTY_FULL
; uses tmp
;-----------------------------------
pwm_duty_limit
	movwf	tmp
	sublw	PWM_DUTY_FULL		;full - new
	btfss	status, c
	retlw	PWM_DUTY_FULL		;new > full
	movf	tmp, w
	return

;-----------------------------------
; Set pwm1 duty from W
; pwm_update must to be called to apply this change
;
; uses tmp and 1 level stack
;-----------------------------------
pwm1_set
	call	pwm_duty_limit
	movwf	pwm_duty1
	return

;-----------------------------------
; Set pwm2 duty from W
; pwm_update must to be called to apply this change
;
; uses tmp and 1 level stack
;-----------------------------------
pwm2_set
	call	pwm_duty_limit
	movwf	pwm_duty2
	return

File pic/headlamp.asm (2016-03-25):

;**********************************************************************
;Led headlamp
;PIC 16F616
;internal 8MHz
;------------------------------
; Jakub Kaderka
; jakub.kaderka@gmail.com
; 2015
;------------------------------
;                                 PIC 16F616
;                         ------------\/-----------
;                        -|Vcc                 VSS|-
;               LED1 PWM -|RA5       RA0/AN0/C1IN+|- LED1 level set
;                    BT2 -|RA4/AN3         RA1/AN1|- LED1 sense
;                    BT1 -|RA3/MCLR      RA2/C1OUT|- LED1 FET
;             LED ground -|RC5       RC0/AN4/C2IN+|- LED2 sense
;	        LED2 FET -|RC4/C2OUT       RC1/AN5|- LED2 level set
;        voltage measure -|RC3/AN7         RC2/AN6|- LED2 PWM
;                         -------------------------
;------------------------------
; Press bt1 for about 2 sec to turn headlamp on
; Press it again for more than 2 sec to turn it off
;
; Short press of bt1 increases light output, bt2 decreases
;
; Led1 is turned on all times except power off state, led2 is controled by
; long press of bt2 (on/off), long press bt2 also switches currently controled
; led's intensity
;**********************************************************************
	LIST P=16F616, R=DEC
	include p16f616.inc
	errorlevel -302

	__CONFIG _CP_OFF & _BOREN_ON & _MCLRE_OFF & _PWRTE_ON & _WDT_OFF & _INTRC_OSC_NOCLKOUT & _IOSCFS_8MHZ

	include headlamp.inc

;**********************************************************************
; Beginning of the program execution
;**********************************************************************
	org 0x0
	goto init

	org 0x4
	goto interrupt

;######################################################################
;all the important parts :)
;######################################################################
	include led.asm
	include pwm.asm
	include ad.asm
	include key.asm
	include actions.asm
;######################################################################
;interrupt
;######################################################################
interrupt
;save registers values
	movwf	w_sav

	swapf	status, w
	movwf	stat_sav

	movf	fsr, w
	movwf	fsr_sav

	clrf	status
;-----------------------------
	btfsc	intcon, t0if
	goto	int_systime
	btfsc	intcon, raif
	goto	int_raif

;ERROR, some other interrupts enabled, fix and return:
	movlw	b'01100000'
	movwf	intcon
	goto	int_end

;wake up from sleep when gie was forgotten enabled, just return
int_raif
	movf	porta, f	;update latches
	bcf	intcon, raif
	goto	int_end

;-----------------------------
;timers for system tasks
; sets run flags after specified period
;
;to keep pwm timing acurate, this part should always take same time
;-----------------------------
int_systime
	decfsz	adc_period_timer, f
	goto	int_systime_ad_wait
	movlw	ADC_PERIOD
	movwf	adc_period_timer
	bsf	task_flags, adc_run	;time to run adc task

int_systime_key
	decfsz	key_period_timer, f
	goto	int_systime_key_wait
	movlw	KEY_PERIOD
	movwf	key_period_timer
	bsf	task_flags, key_run	;time to run key task

	goto	int_pwm

int_systime_ad_wait
	goto	int_systime_key

int_systime_key_wait
	goto	$+1
	goto	int_pwm

;-----------------------------
; Double channel 2048Hz pwm, uses up to 50% of system time
;
; Generates shorter part of the pulse:
;	duty <= 50% : generate high part of pulse
;	duty >= 50% : generate low part of pulse
;
; first, set initial pwm pins values, wait for the length of the shorter
; pulse, then set new pin values and wait for the rest of the time of the longer
; one, finally set the last value
;
; Timing and output settings are determined by preset variables
;	pwm_time1,2 contains timing of the two parts
;	pwm_data pin states in all three parts of pwm execution
;
; Pulse time (0 < pwm_timeX < 256):
;	firtst 8+4*pwm_time1
;	second 19+4*pwm_time1+4*pwm_time2
;
; Because of lowest time consumption code, 100% duty is not possible
;	9us space will exist (equals 99% duty)
;-----------------------------
int_pwm
	bcf	intcon, t0if		;clear
	PWM_SET pstart1, pstart2	;set leds to initial state

;wait for shorter pulse to finish
	movf	pwm_time1, w
	movwf	pwm_count
int_pwm1
	nop
	decfsz	pwm_count, f
	goto	int_pwm1

	PWM_SET	pmiddle1, pmiddle2

;wait for the rest of the time for the second pulse end
	movf	pwm_time2, w
	movwf	pwm_count
int_pwm2
	nop
	decfsz	pwm_count, f
	goto	int_pwm2

	PWM_SET	pend1, pend2
;-----------------------------
;restore register values
int_end
	movf	fsr_sav, w
	movwf	fsr

	swapf	stat_sav, w
	movwf	status

	swapf	w_sav, f
	swapf	w_sav, w
;...............................
	retfie

;######################################################################
;Init
;######################################################################
init
;**************************************
; peripherals
;**************************************
;bank 0
;clear ports
	movlw	0xff
	movwf	porta
	movwf	portc
;bank1
	bsf	status, rp0
;comparators outputs in input state for now
	movlw	b'11011111'
	movwf	trisa
	movlw	b'11011011'
	movwf	trisc

	clrf	wpua		;disable pull ups
	movlw	b'10110011'
	movwf	ansel		;only RC3 and comparators out are analog inputs
;----------------AD--------------------
	movlw	b'01010000'
	movwf	adcon1		;set ADC period - 2us
;bank0
	bcf	status, rp0
	movlw	b'00011101'	;left justified, vdd reference,AD module on
	movwf	adcon0
;------------comparator----------------
	movlw	b'10110000'
	movwf	cm1con0		;output inverted
	movlw	b'10100001'
	movwf	cm2con0
	movlw	0x02
	movwf	cm2con1		;asynchronous outputs, timer1 ignored
;---------------timers-----------------
;tmr0
;bank1
	bsf	status, rp0
	movlw	b'11010001'	;timer0 incremented by internal clock, 1:4 prescaler
	movwf	option_reg
;bank0
	bcf	status, rp0
	clrf	tmr0
;--------------interrupt---------------
	movlw	b'00100000'	;tmr0 interrupt enabled, global disabled for now
	movwf	intcon
;bank1
	bsf	status, rp0
	movlw	0x08
	movwf	ioca		;unmask interrupt on bt1 change
;bank0
	bcf	status, rp0

;-------------status_led---------------
	bcf	ledv
	bsf	pwm1		;turn led on
;**************************************
; variables
;**************************************
	clrf	led1_intensity
	clrf	led2_intensity

	clrf	pwm_duty1
	clrf	pwm_duty2
	call	pwm_update		;init pwm values

	movlw	ADC_LOW_RETRIES
	movwf	adc_low_count
	movlw	ADC_LOW_RETRIES
	movwf	adc_off_count

	movlw	ADC_PERIOD
	movwf	adc_period_timer
	movlw	KEY_PERIOD
	movwf	key_period_timer

	clrf	task_flags

	clrf	buttons
	clrf	mode

;**************************************
; battery check...
;**************************************
;init adc result, checking if voltage is high enough not neccesary, device
; will turn off itself in few us anyway, voltage will be checked when turning on
	call	adc_voltage_check

;enable interrupt -> pwm
	bsf	intcon, gie
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

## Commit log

2015-07-06 first pwm routine
2015-07-06 Somehow working pwm
2015-07-12 Pwm working, ad code added
2015-07-24 PWM and led control works
2015-07-26 Led modes + buttons working, ad disabled
2015-07-29 added pcb design
    [led_driver.kicad_pcb, led_driver.sch]
2015-07-29 3D drawing added
    [body.fcstd, body.step]
2015-09-25 Latest pcb design, leds still on main board
    [led_driver.kicad_pcb]
2015-11-30 Comments in schematic changed
    [led_driver.sch]
2015-12-01 Fixed missing footprint error
    [led_driver.kicad_pcb, led_driver.sch]
2015-12-01 Thermal vias added
    [led_driver.kicad_pcb]
2015-12-03 Cleanup, preparing for manufacturing
    [led_driver.kicad_pcb]
2015-12-07 Cleanup before sending to seedstudio
    [led_driver.kicad_pcb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]
2015-12-08 Divider modified for higher stability and overcurrent protection on fw error
    [led_driver.kicad_pcb, led_driver.sch]
2016-01-10 Renamed gerber extension to required form by manufacturer
2016-01-10 Fixed resistor not in E12
    [led_driver.kicad_pcb, led_driver.sch]
2016-02-10 Created directory for multiple cad parts
    [body.fcstd, body.step]
2016-02-10 Bill of material added
    [BOM.csv]
2016-02-15 fixed MCU name in sources
    [headlamp.asm]
2016-02-15 Fixed comment in schematics
    [led_driver.sch]
2016-02-16 Holes resized to match recommended diameter for screw taps
    [body.fcstd]
2016-02-16 added control knob
    [control_knob.fcstd]
2016-02-16 removed uneeded cad files
    [body.step]
2016-03-19 Corrected control knob dimensions to match prototype
    [control_knob.fcstd]
2016-03-21 Added battery box body
    [box_body.fcstd, box_body.stl]
2016-03-25 Turn off adc during standby
2016-03-25 Switched to 8MHz for more stable light output
2016-03-25 Added low power mode before power off
2016-03-26 Added body drawings, incomplete
    [body.fcstd, control_knob.fcstd]
2016-03-31 Some updates to cad drawings
    [body.fcstd, control_knob.fcstd]
2016-04-02 Added max PWM limit
2016-04-07 Driver pcb moved to separate folder
    [BOM.csv, led_driver.kicad_pcb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]
2016-04-09 Added switch model
    [switch.fcstd, switch.stl]
2016-05-05 added battery box lid
    [box_lid.fcstd, box_lid.stl]
2016-05-05 Returned pcb to single directory
    [BOM.csv, led_driver.kicad_pcb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]
2016-05-06 Added screw knob for battery box
    [knob.fcstd, knob.stl]
2016-05-23 Updated battery box knob
    [knob.fcstd, knob.stl]
2016-06-03 Increased lid depth for bigger connector
    [box_lid.fcstd, box_lid.stl]
2016-06-21 Added bill of materials
2016-06-21 Added lab measurement data
    [Measure_results.csv]
2016-06-21 Chages semicollons to commas in measurement csv
    [Measure_results.csv]
2016-06-22 Updated BOM
    [BOM.csv]
2016-06-22 Added missing parts to BOM
2016-06-29 Added lamp holder
    [holder.fcstd]
